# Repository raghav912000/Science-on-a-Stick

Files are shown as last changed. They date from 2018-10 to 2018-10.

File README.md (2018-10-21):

# Science-on-a-Stick
The thought of this project came when I was working in my physics lab. I made this project to overcome the limitations of performing experiments using conventional apparatus. Through this project, we can verify the value of acceleration due to gravity, Faraday's  Law and Lenz's Law with more accuracy and fewer efforts.  I use Arduino to convert analog value ( voltage across a coil) into digital values and send it to the laptop. I write a python code which receives data send by Arduino and plot the corresponding analog value. Through this curve, we can easily observe the maximum voltage across a coil. We can also verify Lenz's Law by the sinusoidal nature of the curve. I also use hall switch to give an interrupt to Arduino when a magnet passes it. By these interrupts, I can measure the time between any two points with more accuracy.
# trial

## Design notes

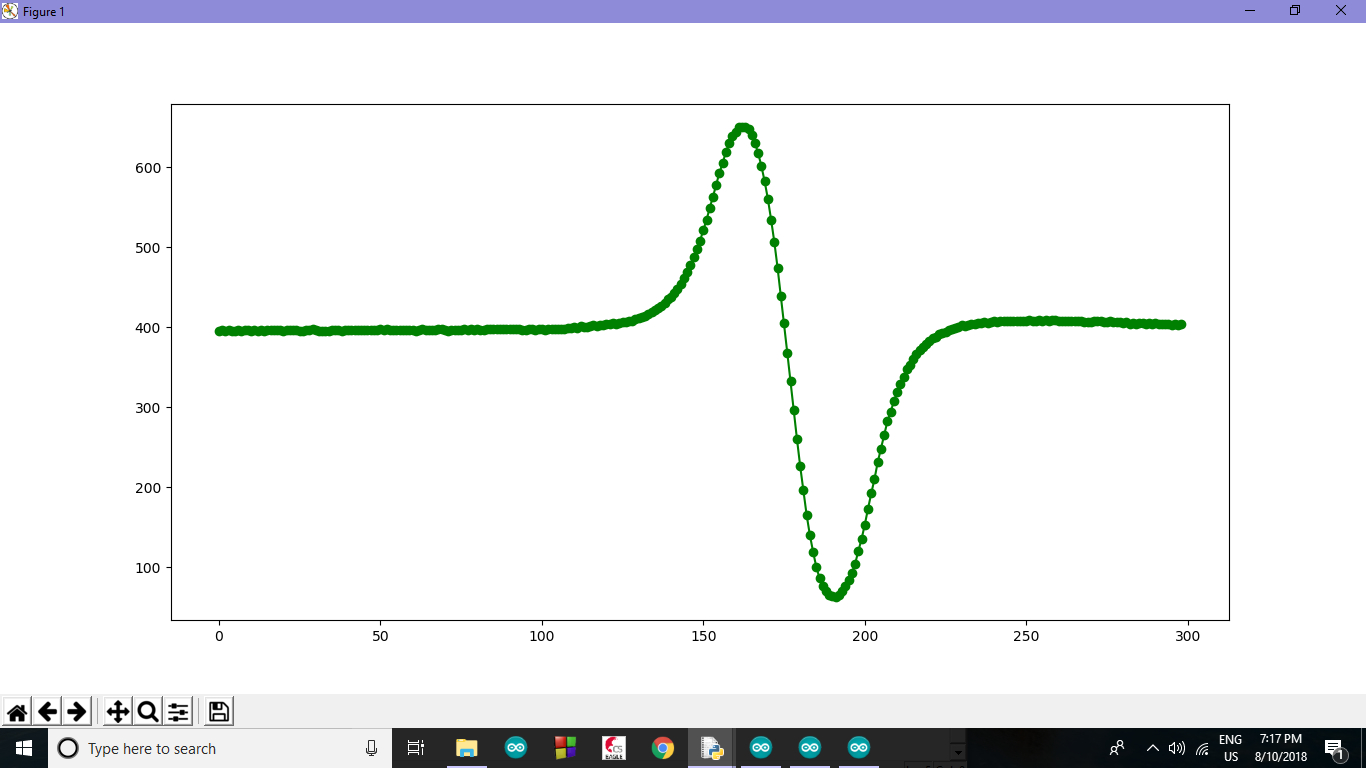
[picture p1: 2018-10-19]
Images/Screenshot (117).png

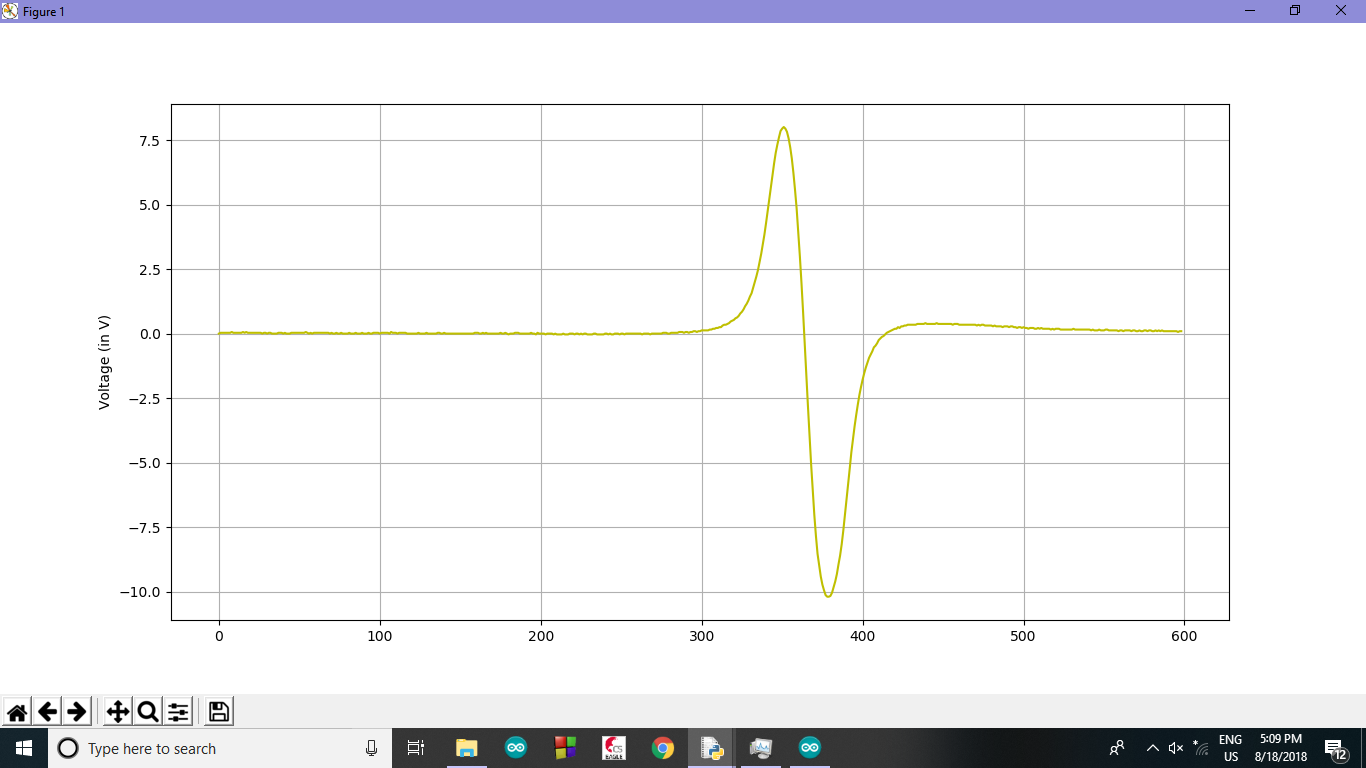
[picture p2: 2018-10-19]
Images/Screenshot (202) - Copy.png

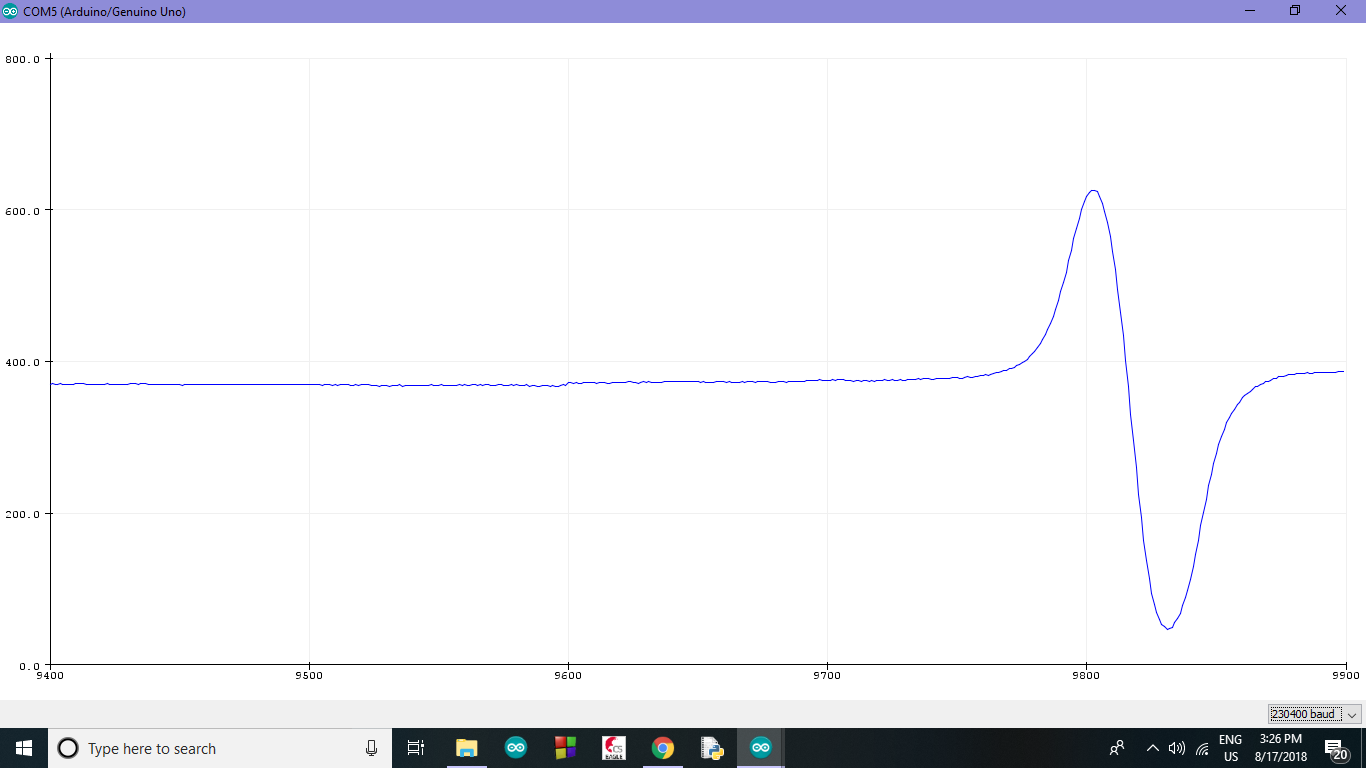
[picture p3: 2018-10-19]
Images/Screenshot (123) - Copy.png

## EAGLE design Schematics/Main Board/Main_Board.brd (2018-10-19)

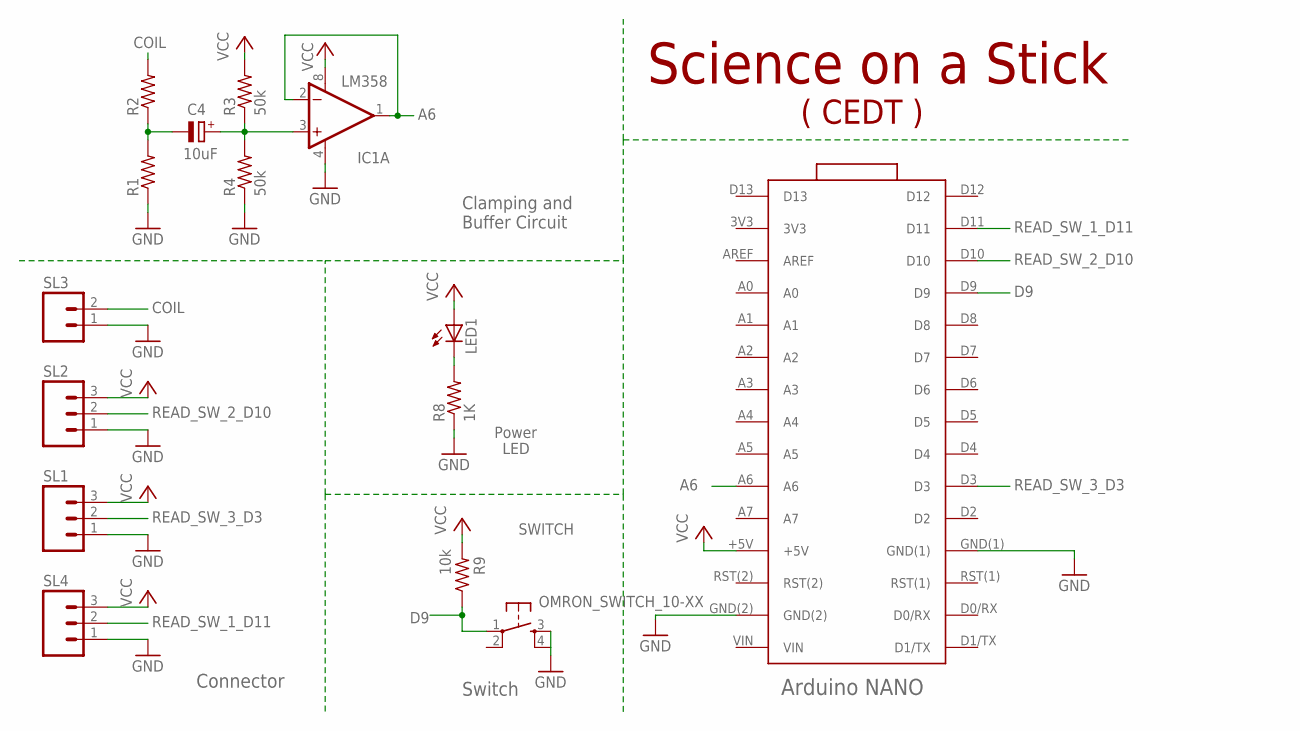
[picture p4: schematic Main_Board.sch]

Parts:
C4: 10uF; E2,5-5
IC1: LM358; DIP08
LED1: LED3MM
R1, R2: RESISTOR0207/7; 0207/7
R3, R4: 50k; 0207/7
R8: 1K; 0207/7
R9: 10k; 0207/7
SL1, SL2, SL4: M03; 03P
SL3: M02; 02P
SWITCH: OMRON_SWITCH_10-XX; B3F-10XX
U$1: ARDUINO_NANO_3_ARDUINO(NANO_3.0); ARDUINO_NANO_3_ARDUINO_NANO_30PIN

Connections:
A6: IC1.1 (OUT), IC1.2 (-IN), U$1.A6
CLAMP_SIGNAL: C4.+, IC1.3 (+IN), R3.1, R4.2
COIL: R2.2, SL3.2
D9: R9.1, SWITCH.1, U$1.D9
GND: IC1.4 (V-), R1.1, R4.1, R8.1, SL1.1, SL2.1, SL3.1, SL4.1, SWITCH.3 (S), SWITCH.4 (S1), U$1.GND(1), U$1.GND(2)
unnamed: C4.-, R1.2, R2.1
unnamed: LED1.K (C), R8.2
READ_SW_1_D11: SL4.2, U$1.D11
READ_SW_2_D10: SL2.2, U$1.D10
READ_SW_3_D3: SL1.2, U$1.D3
VCC: IC1.8 (V+), LED1.A, R3.2, R9.2, SL1.3, SL2.3, SL4.3, U$1.+5V

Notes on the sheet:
Arduino NANO
Science on a Stick
( CEDT )
Power
LED
Switch
Connector
Clamping and Buffer Circuit

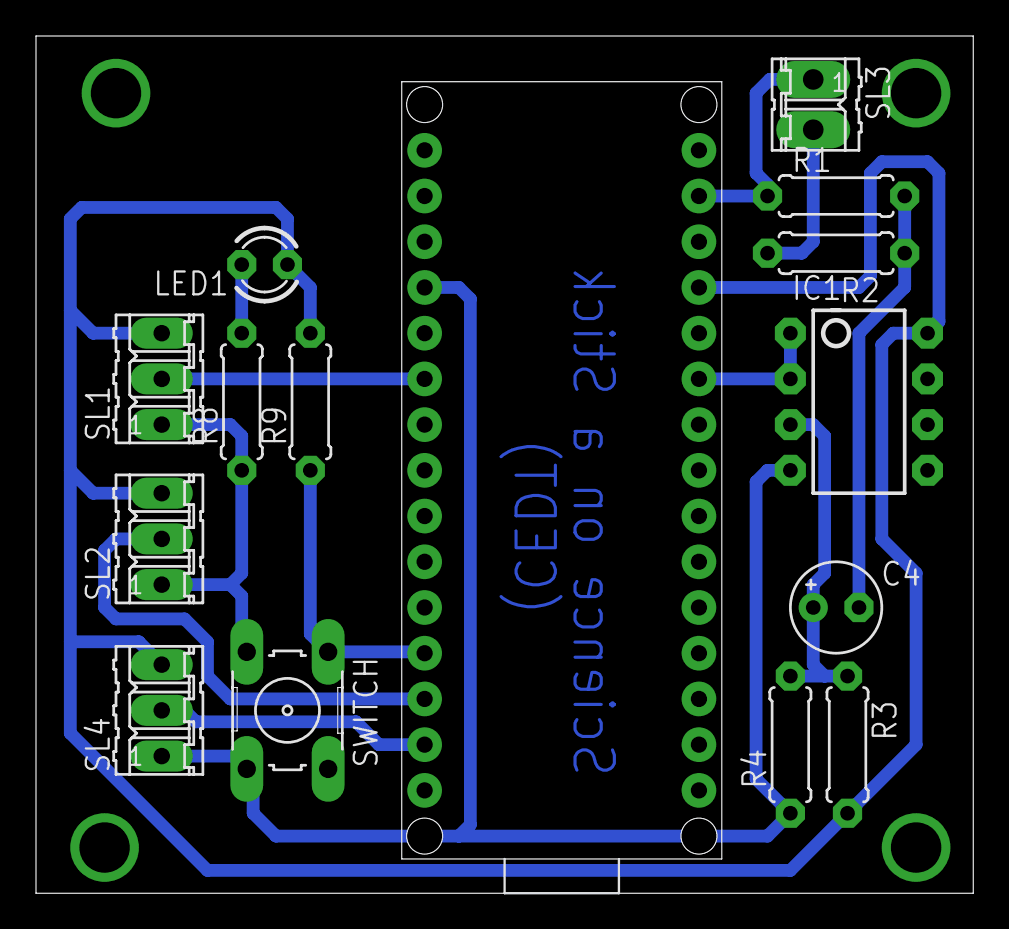
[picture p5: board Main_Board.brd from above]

Board: 2 copper layers, 52.1 x 47.6 mm, 15 parts (0 on the bottom side), 11 nets.

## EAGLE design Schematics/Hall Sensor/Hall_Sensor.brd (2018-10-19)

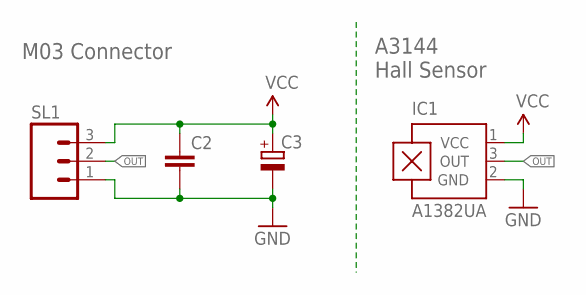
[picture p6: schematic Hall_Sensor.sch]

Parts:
C2: C-EU025-025X050; C025-025X050
C3: CPOL-EUE2,5-6E; E2,5-6E
IC1: A1382UA; SIP3-UA
SL1: M03; 03P

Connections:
GND: C2.2, C3.-, IC1.2 (GND), SL1.1
OUT: IC1.3 (OUT), SL1.2
VCC: C2.1, C3.+, IC1.1 (VCC), SL1.3

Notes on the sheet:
M03 Connector
A3144 Hall Sensor

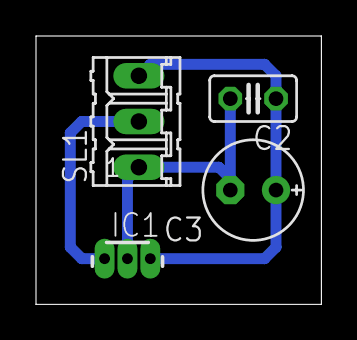
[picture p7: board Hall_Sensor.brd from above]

Board: 2 copper layers, 15.9 x 14.9 mm, 4 parts (0 on the bottom side), 3 nets.

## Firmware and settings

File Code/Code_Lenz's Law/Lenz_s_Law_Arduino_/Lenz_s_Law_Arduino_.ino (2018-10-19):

#define pin A7
#define pin2 10
 
void setup() {
  Serial.begin(230400); 
  //Serial.begin(115200); 
  pinMode(pin,INPUT);
  pinMode(pin2,INPUT);
  pinMode(2,INPUT);
}
 
void loop() {
  while(true){
  while(true){
  if(digitalRead(pin2)==HIGH)
    break;
  }
  while(digitalRead(2)==LOW)
  {
  Serial.println(analogRead(pin));
  }
  Serial.println("-1");
}}

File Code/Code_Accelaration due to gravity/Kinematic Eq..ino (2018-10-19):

#define pin1 10
#define pin2 5
#define pin3 2
long int timet[3];
void setup() 
{
Serial.begin(9600);
pinMode(pin1,INPUT);
pinMode(pin2,INPUT);
pinMode(pin3,INPUT);
}

void loop()
{
while (true)
{
  if(digitalRead(pin1)==HIGH)
  {
    Serial.println(1);
    timet[0]=millis();
    break;
  }
}
while (true)
{
  if(digitalRead(pin2)==HIGH)
  {
    Serial.println(2);
    timet[1]=millis();
    break;
  }
}
while (true)
{
  if(digitalRead(pin3)==HIGH)
  {
    Serial.println(3);
    timet[2]=millis();
    break;
  }
}
Serial.println("Observed Time :");
Serial.println("Time taken between first and second Switch : ");
Serial.println(timet[1]-timet[0]);
Serial.println("Time taken between first and third Switch : ");
Serial.println(timet[2]-timet[0]);/*
Serial.println("Calculated Time :");
Serial.println("Time taken between first and second Switch : ");
Serial.println(235);
Serial.println("Time taken between first and third Switch : ");
Serial.println(424);*/
}

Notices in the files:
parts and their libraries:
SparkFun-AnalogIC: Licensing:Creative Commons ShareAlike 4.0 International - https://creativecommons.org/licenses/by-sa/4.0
